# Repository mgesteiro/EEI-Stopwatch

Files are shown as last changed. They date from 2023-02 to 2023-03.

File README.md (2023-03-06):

# EEI-Stopwatch
Open-source and open-hardware stopwatch for [UVigo's E.E.I. Robotic Competition](https://eei.robots.webs.uvigo.es/).

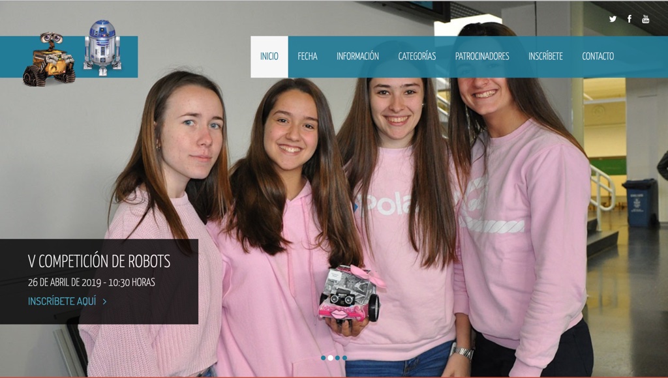
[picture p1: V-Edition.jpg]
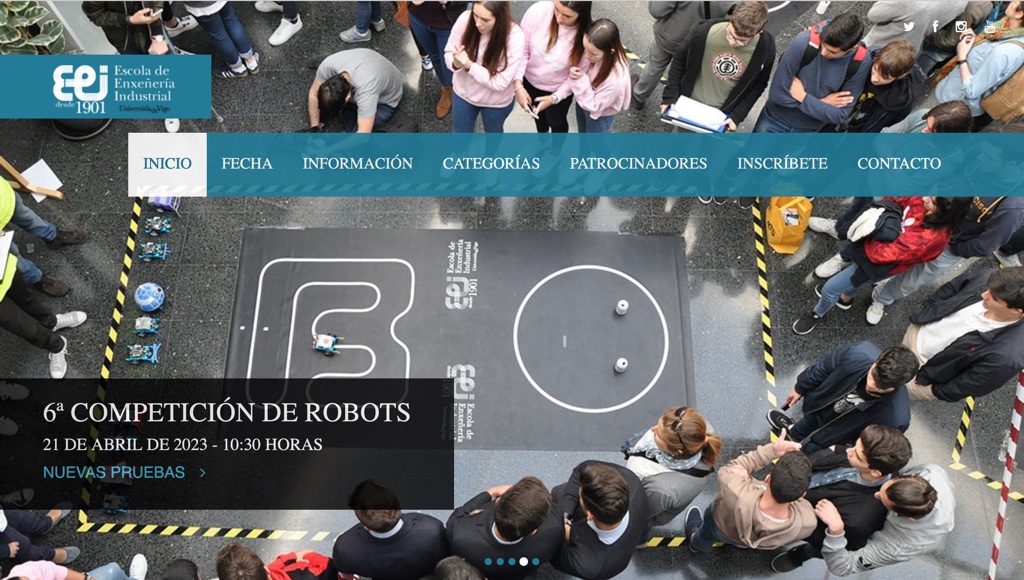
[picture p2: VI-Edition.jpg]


This project has been updated and improved for the **2023 VI edition** of the competition, including a new laser sensor (more accurate and less sensitive to interferences) and a new code base, making it easier to understand, use, configure and adapt.

It's been designed and executed with a minimalistic -yet **highly functional**- intention (it's NOT a toy) while preserving the ***tinkering & learning Maker mindset***, very appropiate and related to the competition nature and goals.

## HOW IT WORKS
The working principle of the **EEI-Stopwatch** is quite simple, although the logic becomes *tricky* easily:

* All the information is shown in a 4-digit 7-segment LED display (*output*).
* User actions are received via a two momentary buttons analog keypad (*input*).
* It has a Tof Laser sensor that measures the distance to the nearest object in front of it continuously.
* When this distance is bellow a configured value, i.e., when ***something passes in front of it***, a detection is triggered: `TDISTANCE` (20 cm by default).
* It gives some room for the object to pass completely to avoid repetitive triggering: `DCWINDOW` (1.9 s by default).
* It uses the internal clock of the microcontroller to measure times.
* It times up to as many laps as configured: `NUMLAPS` (4 by default).
* It shows temporarily the time for each lap after measuring it: `SLWINDOW` (2 s by default).

## OPERATION
The use of the **EEI-Stopwatch** is fairly straightforward and can be done mostly intuitively, but these are the detailed steps:

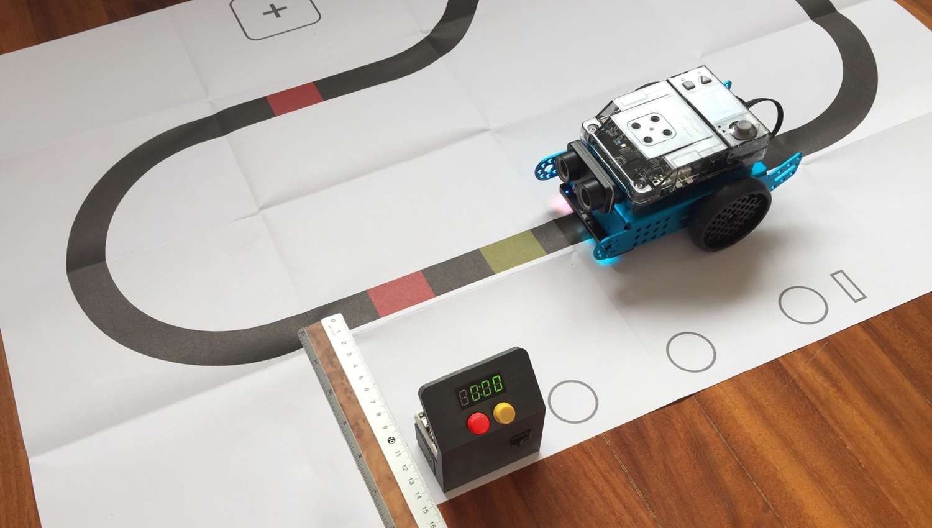
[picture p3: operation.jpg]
Operation


1. **Turn it ON** using the main frontal switch (position *1*): you should see a start-up animation (a *racing LED*). If any problem is detected, an error message will be shown, indicating that the device must be checked/serviced. Make sure also that it is correctly charged!
2. Once started, the EEI-Stopwatch is in ***Distance Measuring Mode***: it shows the distance -in centimeters- to the nearest object in front of the sensor.
	* Use this to **position it about 15-20 cm** from the *racing line*: use your own hand as reference for the sensor. Ideally, position it in the side of a straitgh line, perpendicular to it (like in the picture).
	* Once positioned, **clear all the objects** in front of it (to avoid *false triggers*) and **press the yellow button** to initiate the ***Stopwatch Mode***.
3. Once in the ***Stopwatch Mode***, the time won't start until it detects a *passing object* (anything at less than 20 cm): it's time to put the robot in the track -behind the stopwatch line- and start it (racing time!).
	* When the **robot is detected** (as passing in front of it), the stopwatch **starts measuring** the time, and does so until the robot is detected again, **storing the lap time** in that precise moment.
	* After each lap, the stopwatch **shows temporarily the previous lap time** (during 2 seconds) and then continues to show the current lap time, until the robot is detected again, repeating the process.
	* There are two possible options now: you can **wait until the robot completes all the laps** that the EEI-Stopwatch can measure in one go (4 by default), or you can **press the yellow button to abort** the process (discarding the current lap). In either case, the EEI-Stopwatch enters the ***Results Mode***.
4. In the ***Results Mode***, you can review all the lap times stored in this go: press the yellow button to cycle through them. Take into account that if the process was aborted, some of the laps may have a *0:00* time.
5. **RESET:** if you **long-press** the red button (during 1 second at least), the EEI-Stopwatch is reset, clearly showing it with a *RESET animation*, and entering the ***Stopwatch Mode*** again (step 3).

**CHARGING:** The EEI-Stopwatch is **battery-powered** (an 18650 Li-ion cell), and can be recharged using any typical 5V micro-USB mobile charger: plug it in the micro-USB connector of the case and watch how the status light changes (through the small hole by its side). NOTE: pay attention to not confuse the USB connector in the Arduino Nano with the one corresponding to the battery charger.

**RESOLUTION:** The EEI-Stopwatch has a configured **maximum resolution of ~5 hundredths** of a second (i.e. 50 ms), determined mostly by the Laser sensor, as the result of a balance between accuracy, interference resilience and responsiveness. It is more than good enough for our application, but feel free to read about it in the configuration section of the code and fine-tune it to your needs.

## 3D

All the **3D parts** (available in the [`3D`](3D) folder) were created using the open-source and free software [FreeCAD](https://www.freecad.org). You can find there also all the STL files ready to be sliced and 3D printed, with **no supports** required at all: it's a very easy print.

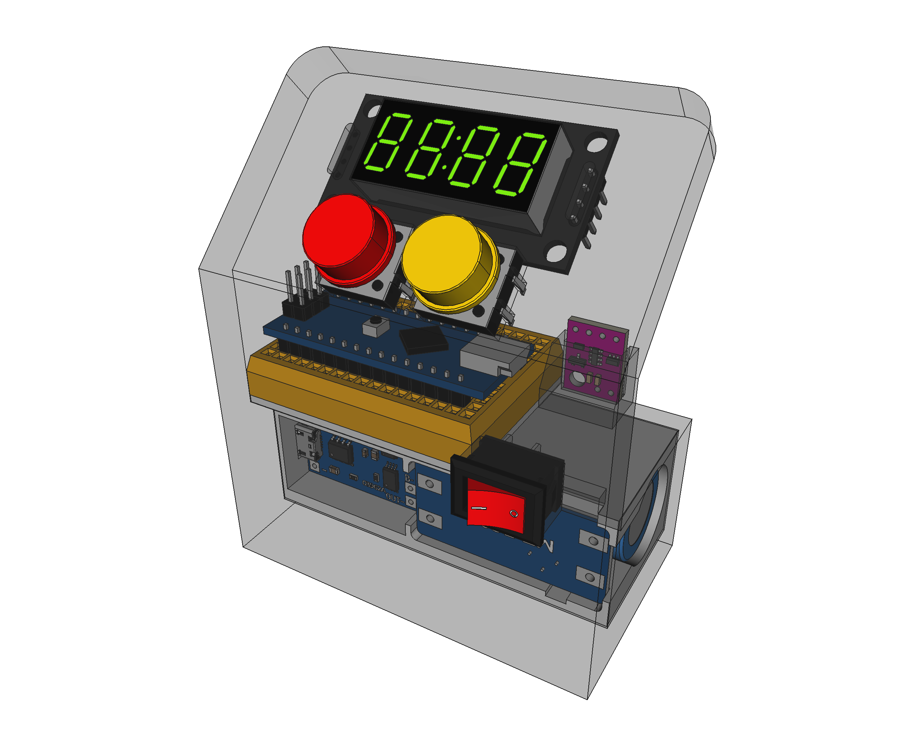
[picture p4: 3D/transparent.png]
transparent


Before printing the pieces, make sure that the dimensions of the electronic parts match: tolerances of the 3D models are *quite tight* and I've already found modules with huge differences in size.

## ELECTRONICS

This is the schematic of the system, created using the open-source software [Fritzing](https://fritzing.org) and available in the [`electronics`](electronics) folder.



The bottom part is the **powerbank** subsystem that provides 5V to the device and is rechargable (using any *typical* 5V micro-USB mobile charger). The top part contains the **4-digit display**, the **ToF laser sensor** and the **analog keypad** (two buttons) along with the **main microcontroller** (an Arduino Nano).

## CODE

The EEI-Stopwatch is powered by an **Arduino Nano** which can be programmed with the [Arduino IDE](https://www.arduino.cc/en/software). The code is **thoroughly commented and documented**, and available in the [`code/chrono`](code/chrono) folder:

* There are a number of configuration parameters at the beggining of the `chrono.ino` file, if you wan't to fine-tune or adapt the operation to your needs (e.g. the number of laps to store, or the different clearing windows).
* Requires two external libraries: [TM1637TinyDisplay](https://github.com/jasonacox/TM1637TinyDisplay) and [VL53L0X](https://github.com/pololu/vl53l0x-arduino) (directly available within the Arduino IDE library manager).
* Includes also two local *ad-hoc* libraries: **`AKeypad-lib.h`** and **`Stopwatch.h`** (both *self-explanatory*)

## ASSEMBLY

In the [`assembly`](assembly) folder there is a 20 step guide to assemble the **EEI-Stopwatch**, including the powerbank itself.

**NOTE:** the assembly guide hasn't been updated to the latest 2023 revision but is still mostly relevant as only two things changed

* The IR sensor has been changed by a ToF Laser sensor
* Some of the connections have been updated accordingly (see the [new schematic](#electronics))

## REFERENCES

* UVigo's E.E.I. Robotic Competition: [eei.robots.webs.uvigo.es](https://eei.robots.webs.uvigo.es/)
* 4-digit 7-segment LED display library: [github.com/jasonacox/TM1637TinyDisplay](https://github.com/jasonacox/TM1637TinyDisplay)
* VL53L0X Tof Laser Sensor library: [github.com/pololu/vl53l0x-arduino](https://github.com/pololu/vl53l0x-arduino)
* VL53L0X ToF Laser Sensor datasheet: [www.digikey.com/en/datasheets/stmicroelectronics/stmicroelectronics-endm00279086](https://www.digikey.com/en/datasheets/stmicroelectronics/stmicroelectronics-endm00279086)
* My FreeCAD 3D models repository: [github.com/mgesteiro/FreeCAD-models](https://github.com/mgesteiro/FreeCAD-models)
* My Fritzing parts repository: [github.com/mgesteiro/fritzing-parts](https://github.com/mgesteiro/fritzing-parts)
* **FreeCAD** 3D CAD modelling software: [www.freecad.org](https://www.freecad.org)
* **Fritzing** schematics and PCB modelling software: [fritzing.org](https://fritzing.org)

## LICENSE

This work is licensed under the [GNU General Public License v3.0](LICENSE-GPLV30). All media and data files that are not source code are licensed under the [Creative Commons Attribution 4.0 BY-SA license](LICENSE-CCBYSA40).

More information about licenses in [Opensource licenses](https://opensource.org/licenses/) and [Creative Commons licenses](https://creativecommons.org/licenses/).

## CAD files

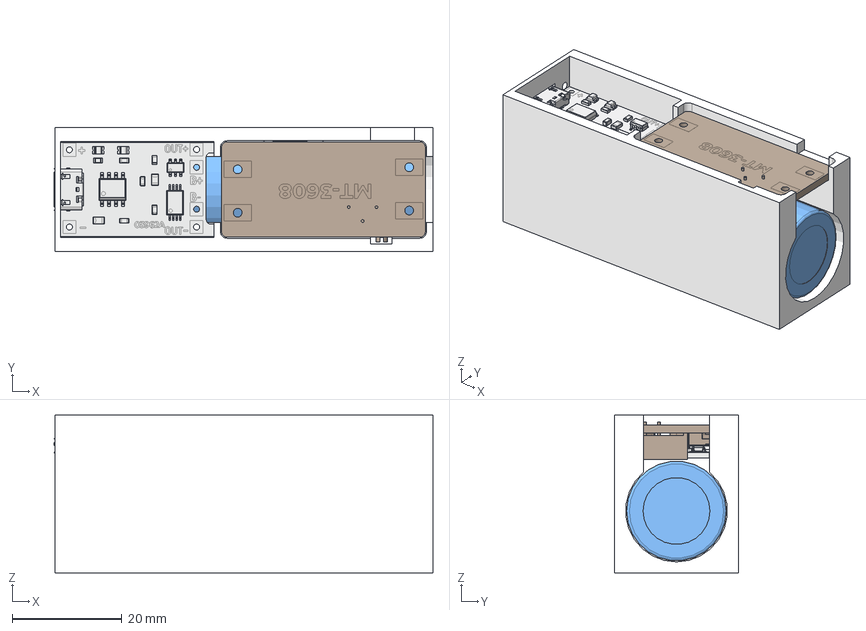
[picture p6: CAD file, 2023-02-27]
3D/powerBank.FCStd
69.2 x 22.6 x 28.8 mm
03962A
MT-3608
Body-powerBank

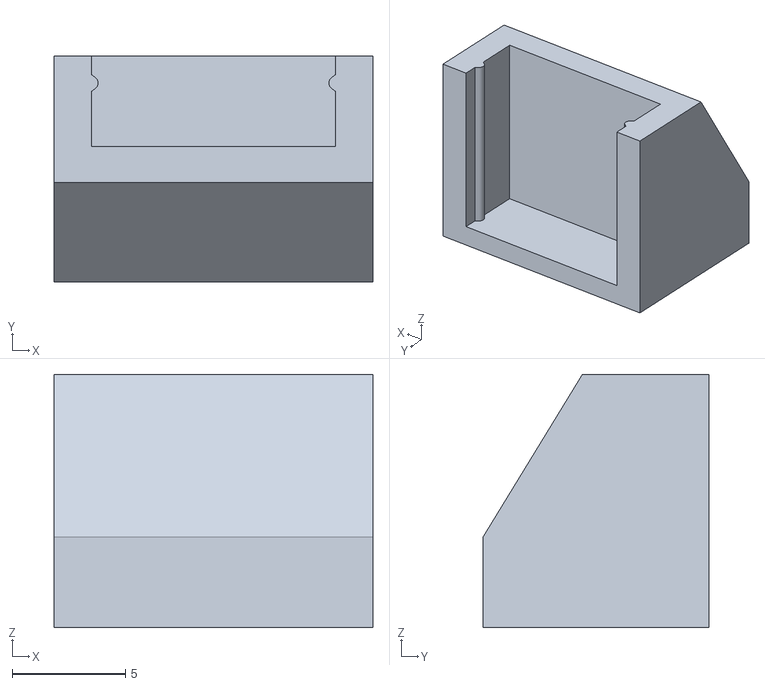
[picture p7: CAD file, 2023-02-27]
3D/tofsupport.stl
14.1 x 10.0 x 11.2

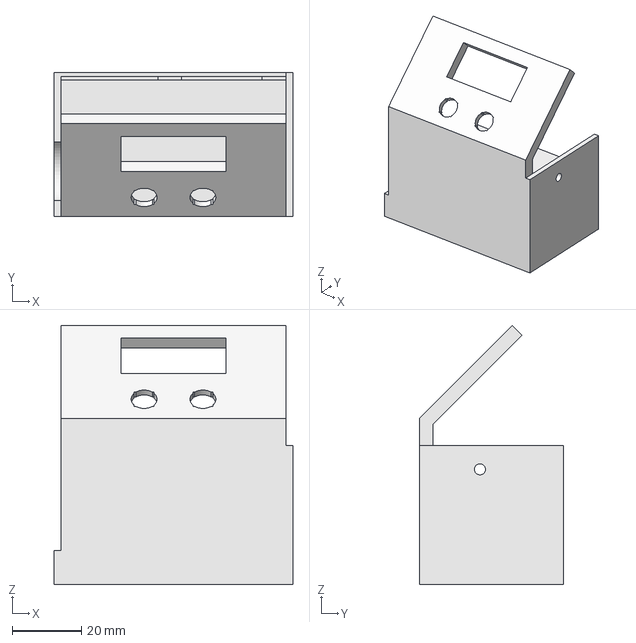
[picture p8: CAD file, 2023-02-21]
3D/chasis.FCStd
69.0 x 41.7 x 74.9 mm

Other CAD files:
3D/chasis.stl
3D/powerBank.stl

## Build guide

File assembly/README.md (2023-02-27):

# EEI-Stopwatch assembly GUIDE
Stopwatch for [UVigo's E.E.I. Robotic Competition](https://eei.robots.webs.uvigo.es/).

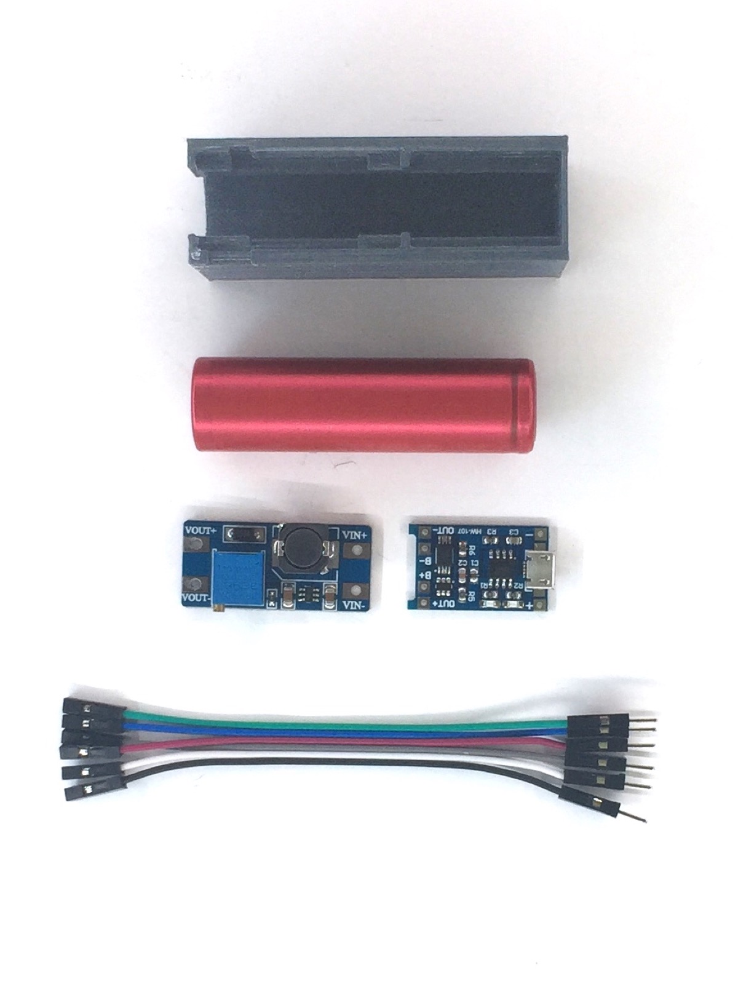
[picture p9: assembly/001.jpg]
Step-01


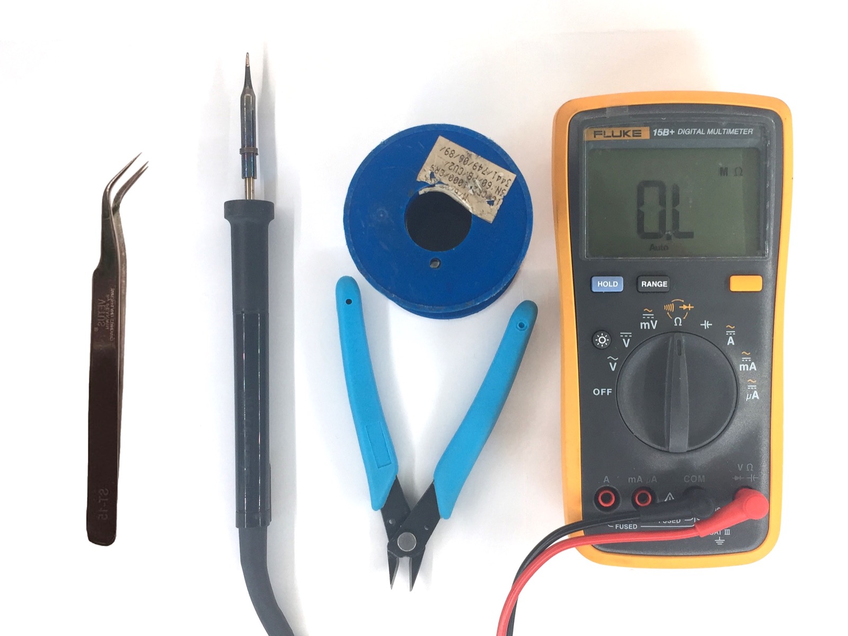
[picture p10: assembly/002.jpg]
Step-02


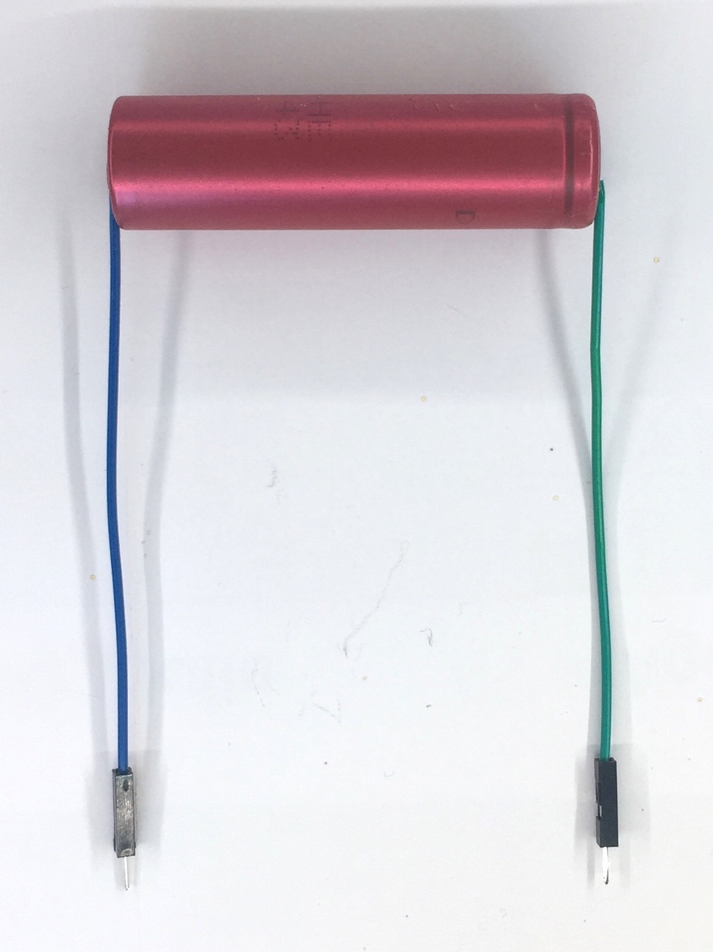
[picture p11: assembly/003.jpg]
Step-03


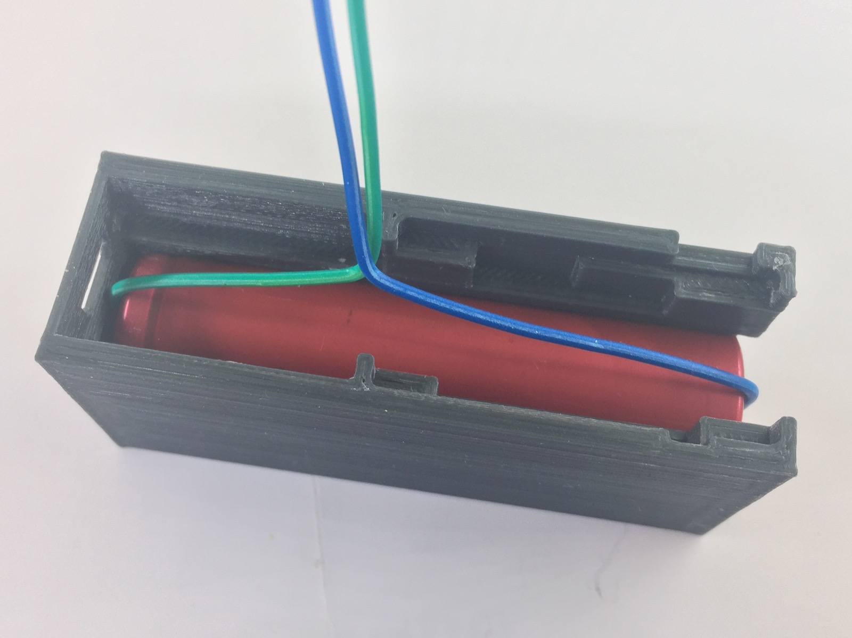
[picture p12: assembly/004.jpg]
Step-04


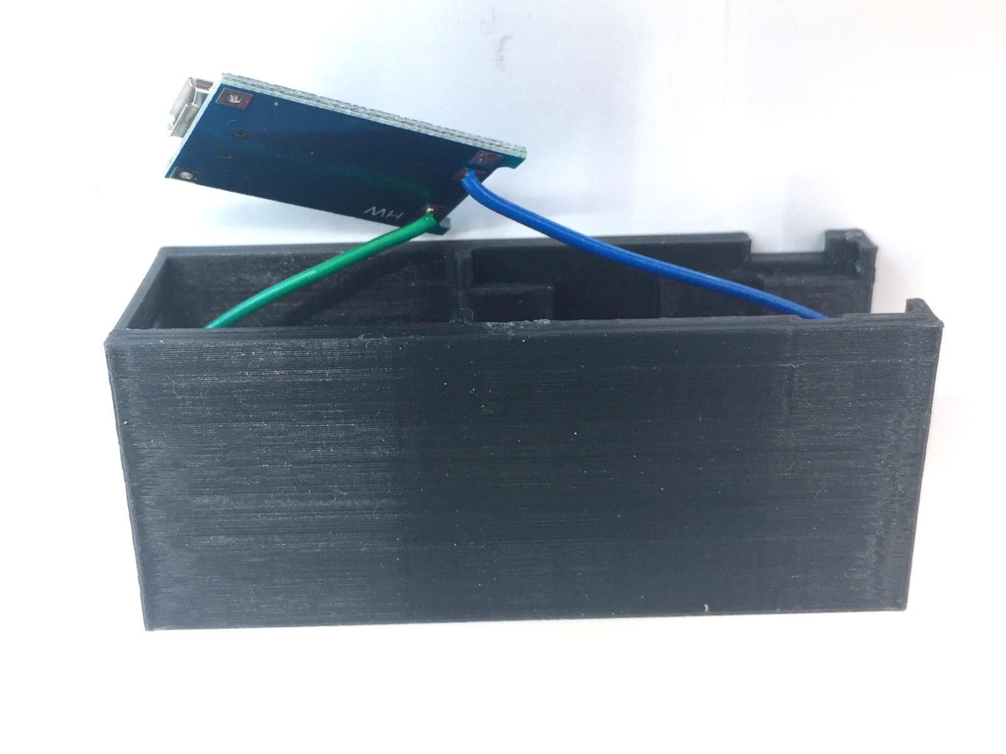
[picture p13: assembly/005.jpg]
Step-05


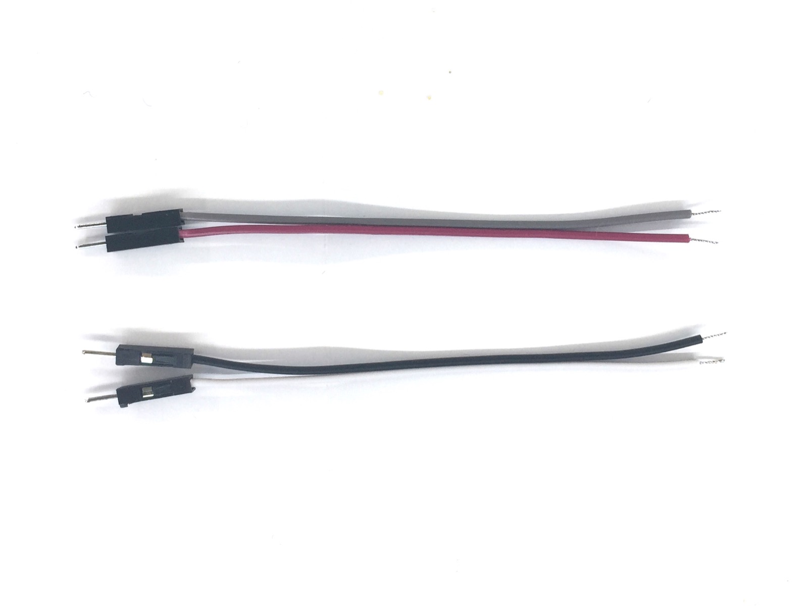
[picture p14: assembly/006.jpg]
Step-06


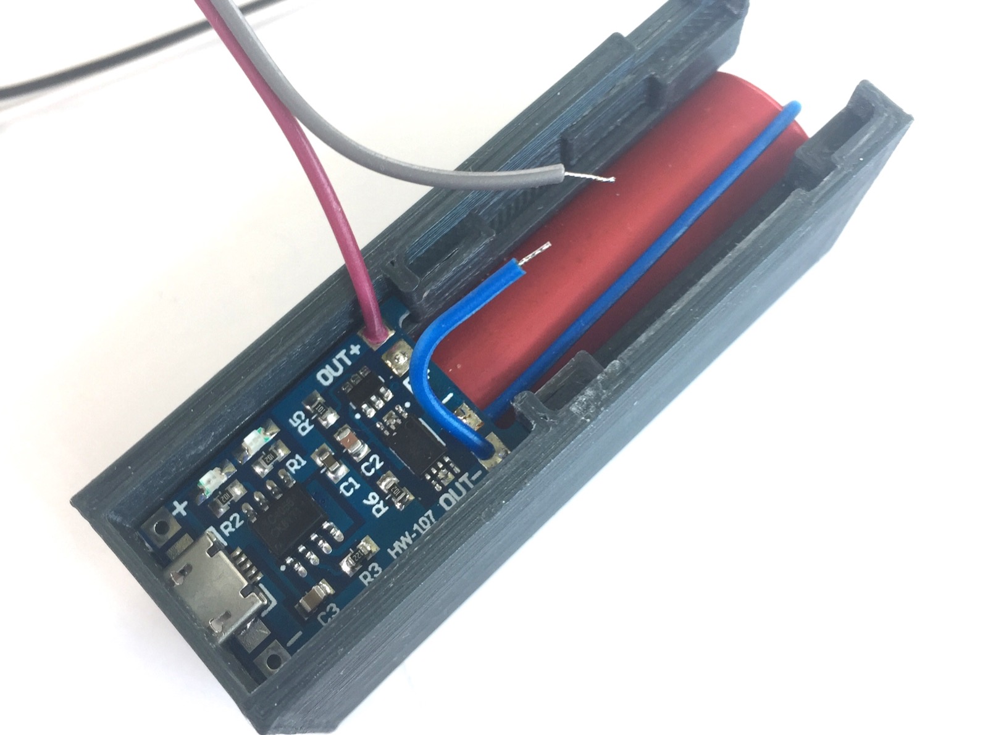
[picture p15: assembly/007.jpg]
Step-07


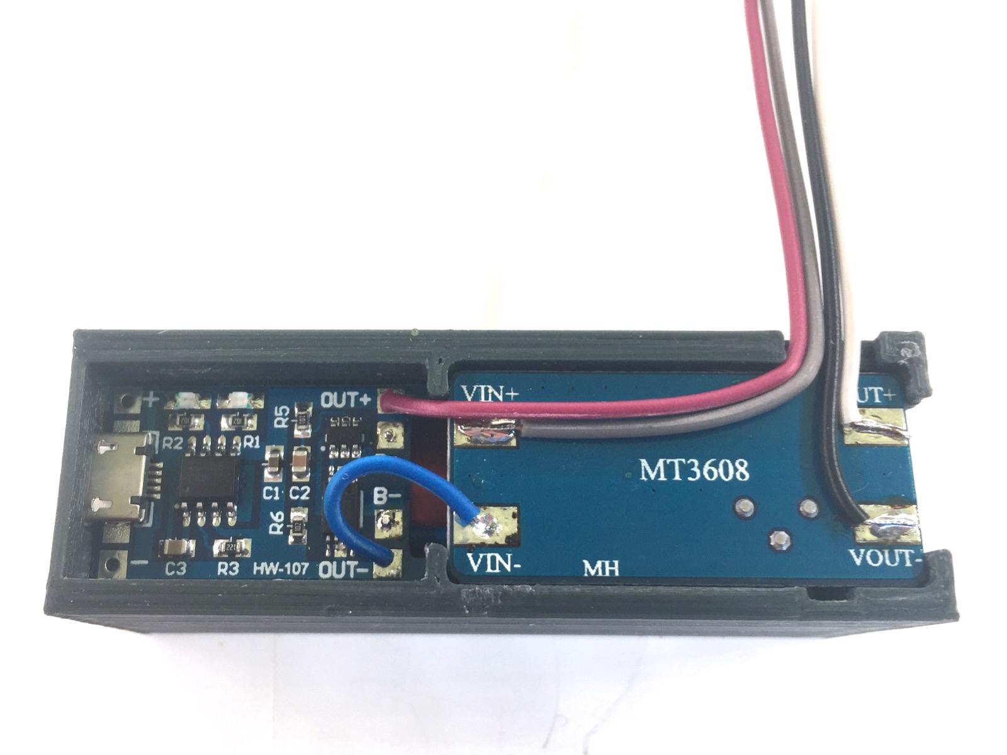
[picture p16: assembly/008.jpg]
Step-08


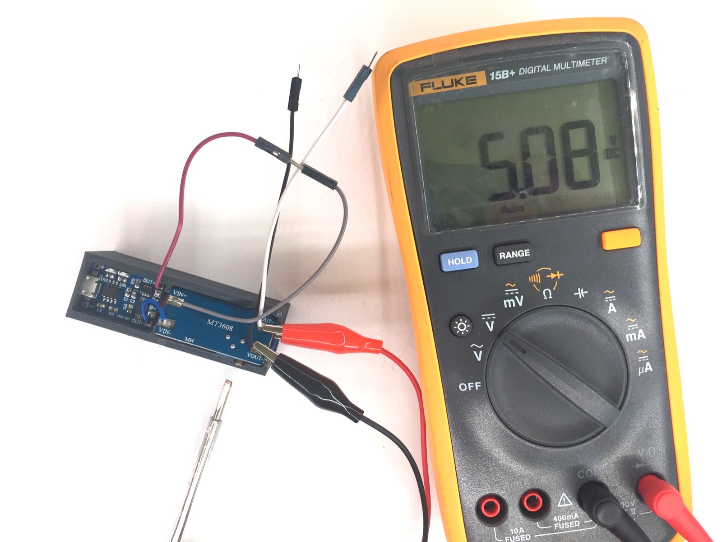
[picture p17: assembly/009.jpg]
Step-09


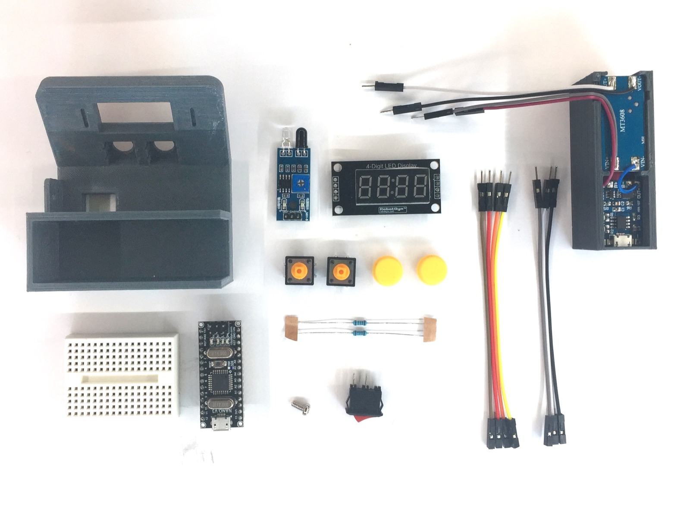
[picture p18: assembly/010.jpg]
Step-10


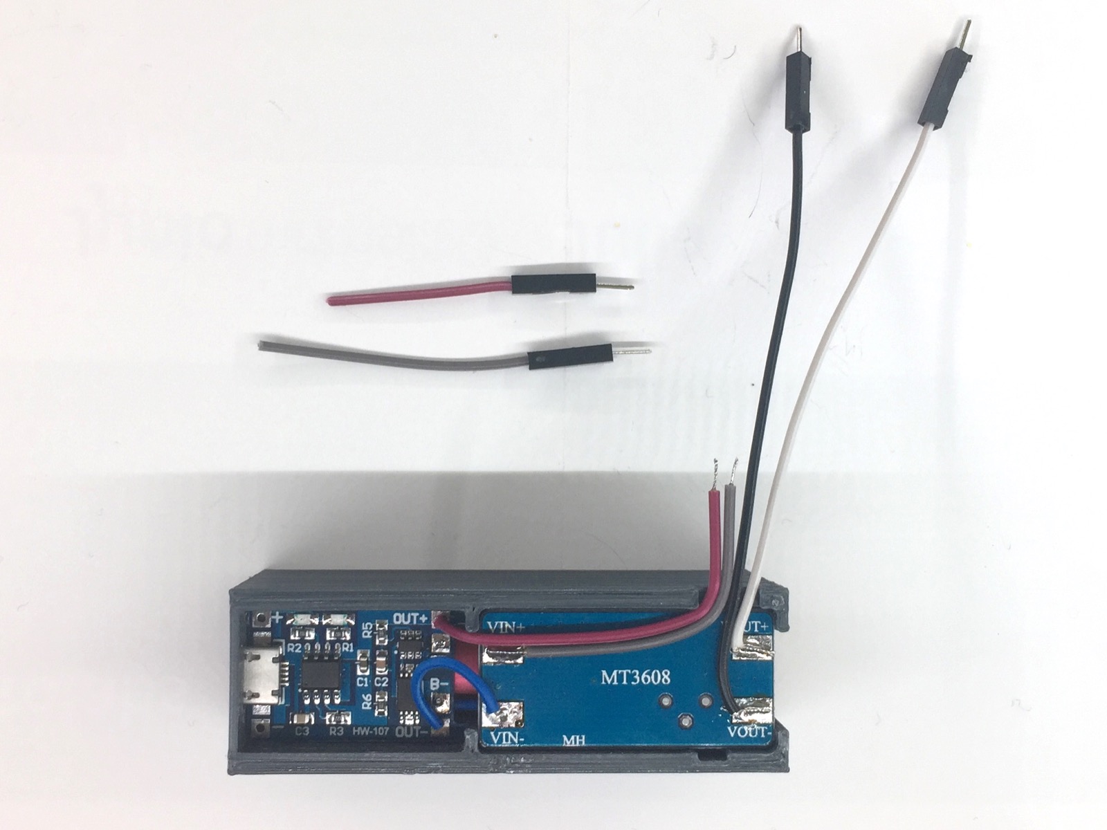
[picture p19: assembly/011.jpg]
Step-11


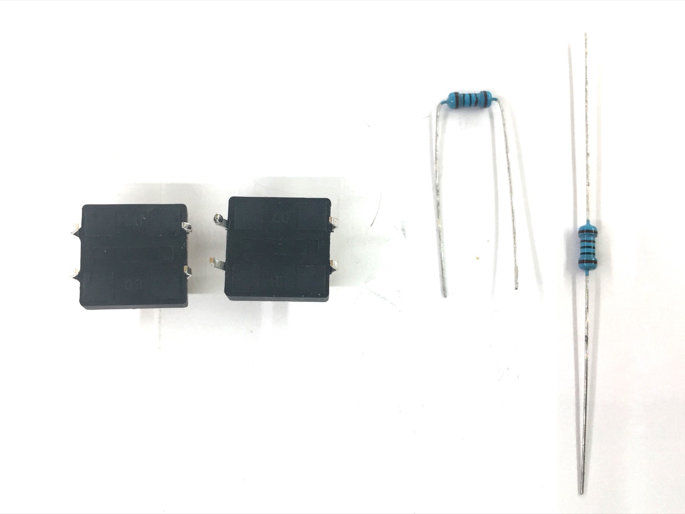
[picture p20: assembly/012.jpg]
Step-12


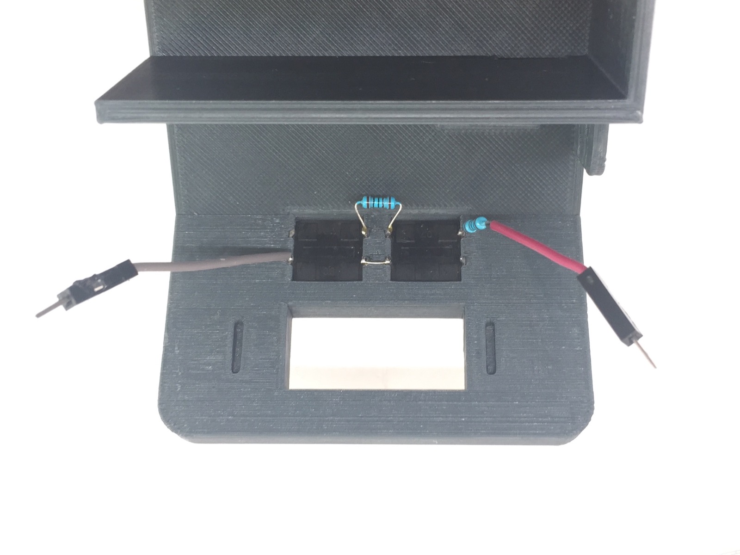
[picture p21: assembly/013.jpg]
Step-13


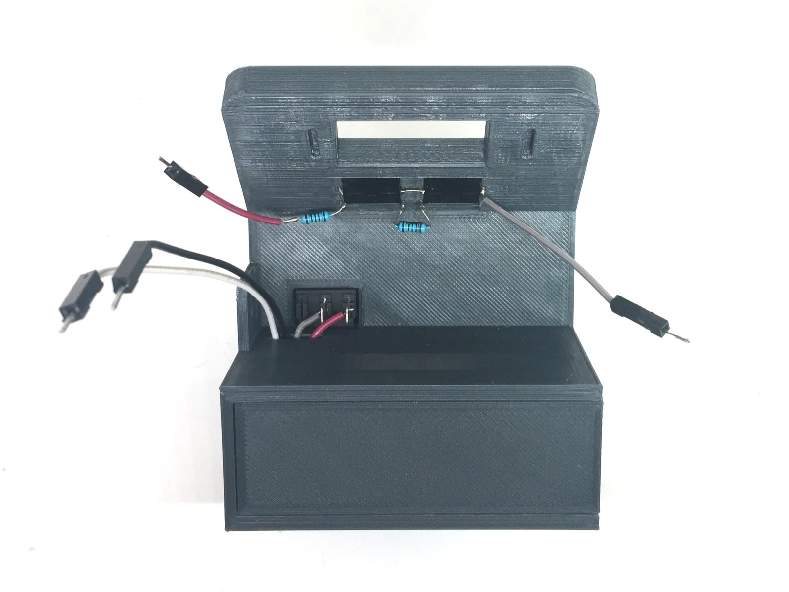
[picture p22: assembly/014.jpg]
Step-14


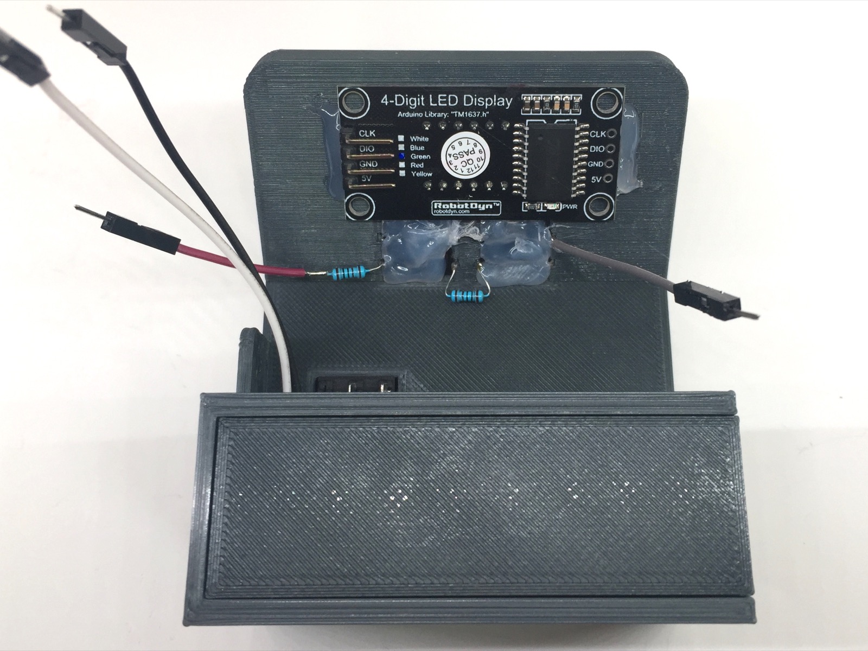
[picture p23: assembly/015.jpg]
Step-15


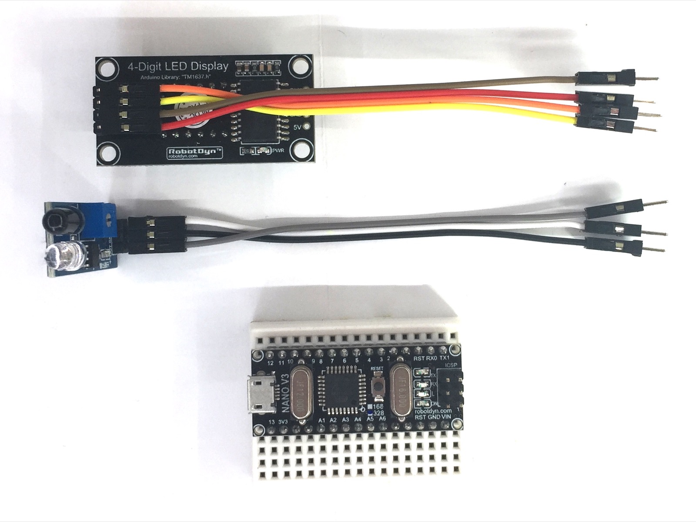
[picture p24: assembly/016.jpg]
Step-16


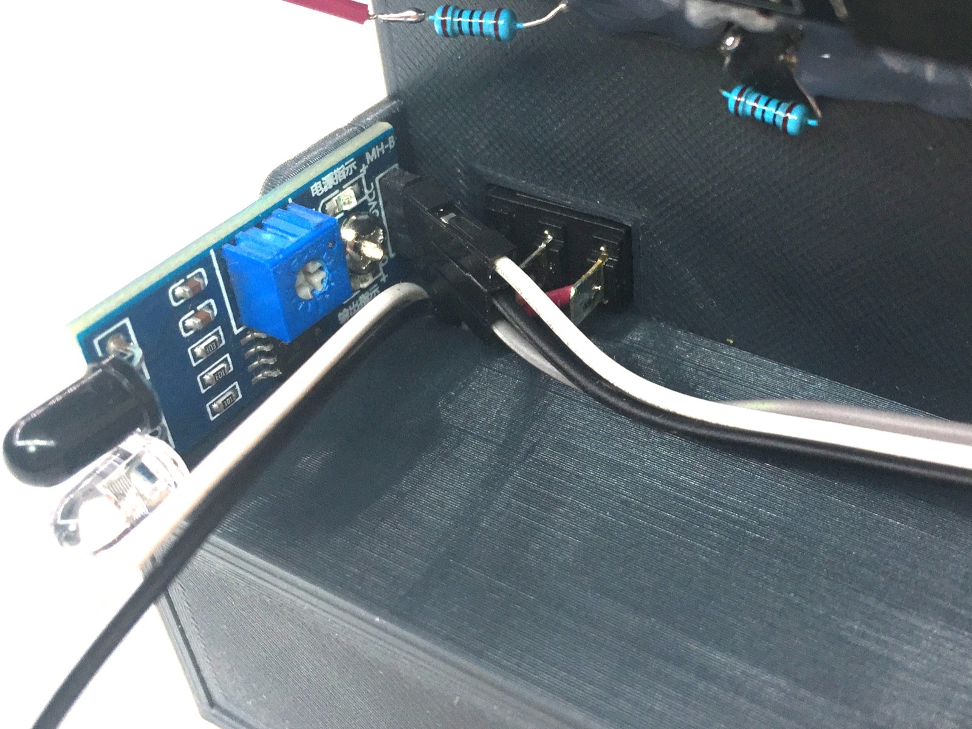
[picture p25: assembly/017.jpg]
Step-17


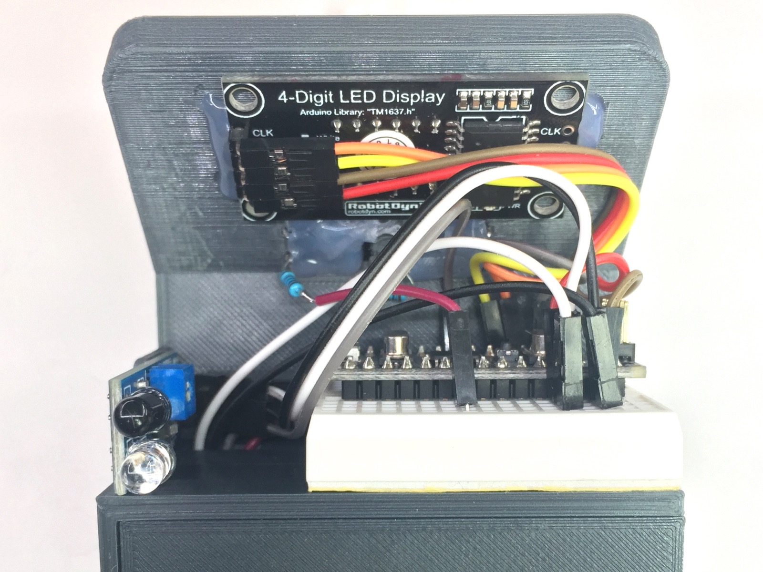
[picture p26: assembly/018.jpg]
Step-18


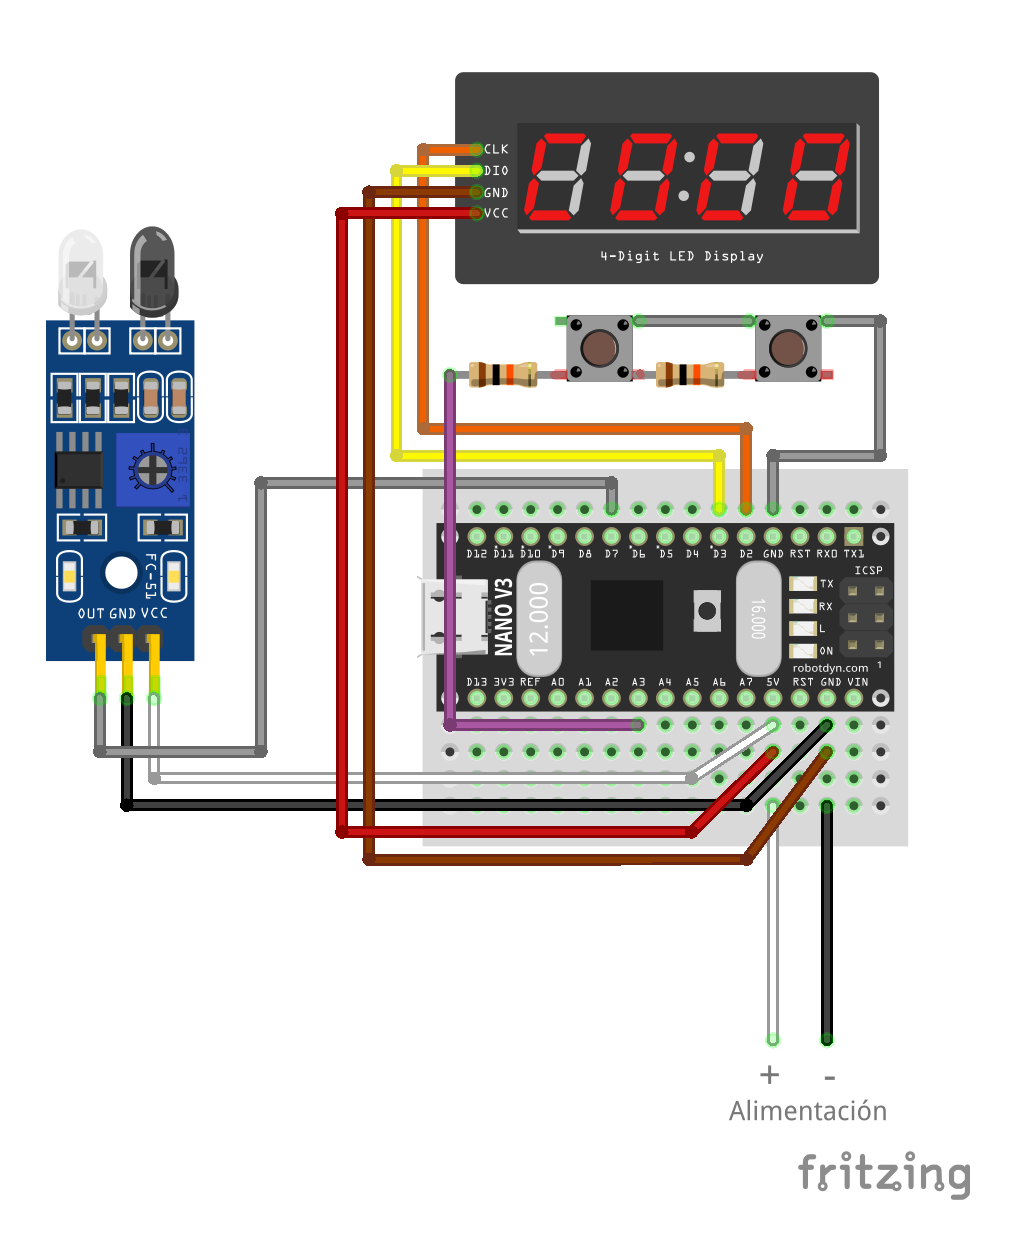
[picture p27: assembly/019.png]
Step-19


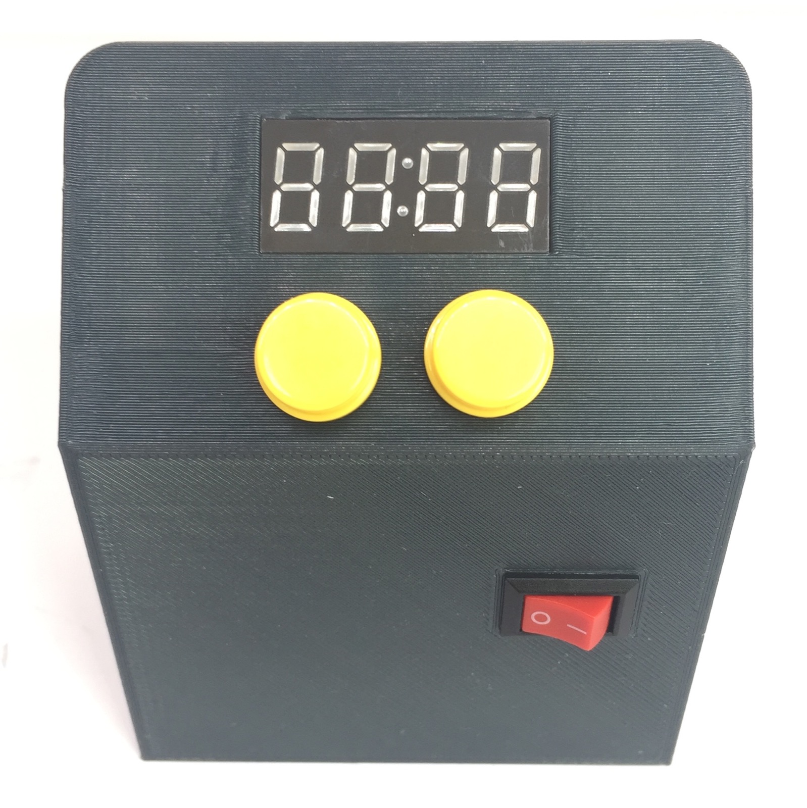
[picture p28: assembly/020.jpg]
Step-20


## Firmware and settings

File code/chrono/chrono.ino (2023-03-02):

/**
 * E.E.I. Stopwatch
 * A stopwatch for UVigo's E.E.I. Robotic Competition - https://eei.robots.webs.uvigo.es/
 *
 * @file      EEI-Stopwatch.ino
 * @author    mgesteiro
 * @date      20231702
 * @version   1.0.0
 * @copyright mgesteiro, OpenSource with LICENSE GPLv3
 * @note      Required libraries: TM1637TinyDisplay, Pololu's VL53L0X
 */

#define PROGRAM "E.E.I. Stopwatch"
#define VERSION "1.0.0"

// Configuration
#define NUMLAPS  4     // Number of Laps to store (maximum 10)
#define TRIGGERD 200   // Trigger Distance in mm: less than this is considered a "detection"
#define DCWINDOW 1900  // Detect Clear Window in ms: no more detections triggered during this time
#define SLWINDOW 2000  // Show Lap Window in ms: how long we show previous lap time while counting

/* Advanced: timing resolution
 * This is the 'time budget' value for the ToF laser sensor: time allowed to measure a distance.
 * The minimum value depends on the hardware revision (18700 in my case). Check your vendor's datasheet.
 * The bigger the number, the more accurate it gets measuring the distance and the less prone to
 * interference, but also the less responsive it becomes, as it requires more time for each measure.
 * The default factory value is ~33000 (i.e. ~33 ms). A value of 20000 means that the fastest it can
 * take a measure is 20 ms, thus becoming by de facto the maximum stopwatch timing resolution.
 * Use a value of 0 to let the device use its factory default.
 */
#define RESOLUTION 50000  // in µs

// Includes
#include <Arduino.h>
#include "Stopwatch.h"
#include "AKeypad-lib.h"
#include <TM1637TinyDisplay.h>
#include <VL53L0X.h>

// Stopwatch
Stopwatch sw(NUMLAPS);
uint8_t whatLap = 0;
uint32_t finishShowLapTime = 0;

// Keypad
#define AKP_PIN A3
#define K_YELLOW 1
#define K_RED 2
const int16_t AKP_VALUES[] = {550, 390};  // 22Kohm resistors
AKeypad keypad(AKP_PIN, 2, AKP_VALUES);


// TM1637TinyDisplay - 4 Digit Display
#define CLK 2
#define DIO 3
TM1637TinyDisplay display(CLK, DIO);

// Initial animation
// @see https://jasonacox.github.io/TM1637TinyDisplay/examples/7-segment-animator.html
const uint8_t INTRO_A[][4] PROGMEM = {
	{ 0x00, 0x00, 0x00, 0x00 },
	{ 0x10, 0x00, 0x00, 0x00 },
	{ 0x20, 0x00, 0x00, 0x00 },
	{ 0x01, 0x00, 0x00, 0x00 },
	{ 0x00, 0x01, 0x00, 0x00 },
	{ 0x00, 0x00, 0x01, 0x00 },
	{ 0x00, 0x00, 0x00, 0x01 },
	{ 0x00, 0x00, 0x00, 0x02 },
	{ 0x00, 0x00, 0x00, 0x04 },
	{ 0x00, 0x00, 0x00, 0x08 },
	{ 0x00, 0x00, 0x08, 0x00 },
	{ 0x00, 0x08, 0x00, 0x00 },
	{ 0x00, 0x10, 0x00, 0x00 },
	{ 0x00, 0x20, 0x00, 0x00 },
	{ 0x00, 0x01, 0x00, 0x00 },
	{ 0x00, 0x00, 0x01, 0x00 },
	{ 0x00, 0x00, 0x02, 0x00 },
	{ 0x00, 0x00, 0x04, 0x00 },
	{ 0x00, 0x00, 0x08, 0x00 },
	{ 0x00, 0x08, 0x00, 0x00 },
	{ 0x08, 0x00, 0x00, 0x00 },
	{ 0x10, 0x00, 0x00, 0x00 },
	{ 0x20, 0x00, 0x00, 0x00 },
	{ 0x01, 0x00, 0x00, 0x00 },
	{ 0x00, 0x01, 0x00, 0x00 },
	{ 0x00, 0x00, 0x01, 0x00 },
	{ 0x00, 0x00, 0x00, 0x01 },
	{ 0x00, 0x00, 0x00, 0x02 },
	{ 0x00, 0x00, 0x00, 0x04 },
	{ 0x00, 0x00, 0x00, 0x08 },
	{ 0x00, 0x00, 0x08, 0x00 },
	{ 0x00, 0x08, 0x00, 0x00 },
	{ 0x08, 0x00, 0x00, 0x00 },
	{ 0x18, 0x00, 0x00, 0x00 },
	{ 0x38, 0x00, 0x00, 0x00 },
	{ 0x39, 0x00, 0x00, 0x00 },
	{ 0x39, 0x01, 0x00, 0x00 },
	{ 0x39, 0x01, 0x01, 0x00 },
	{ 0x39, 0x01, 0x01, 0x01 },
	{ 0x39, 0x01, 0x01, 0x03 },
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
};
// Reset animation
const uint8_t RESET_A[][4] PROGMEM = {
	{ 0x00, 0x06, 0x30, 0x00 },
	{ 0x00, 0x46, 0x70, 0x00 },
	{ 0x40, 0x06, 0x30, 0x40 },
	{ 0x30, 0x06, 0x30, 0x06 },
	{ 0x30, 0x30, 0x06, 0x06 },
	{ 0x36, 0x00, 0x00, 0x36 },
	{ 0x30, 0x00, 0x00, 0x06 },
	{ 0x00, 0x00, 0x00, 0x00 }
};

// VL53L0X ToF sensor
VL53L0X tof;
uint32_t detectionClearTime = 0;

// working modes
uint8_t wmode = 0;
#define M_DISTANCE 1
#define M_STOPWATCH 2
#define M_RESULTS 3


/*********************************************************************************************
 *
 *   S E T U P   &   L O O P
 *
 */

void setup() {
	// Serial port banner
	Serial.begin(115200);
	Serial.print(PROGRAM);
	Serial.print(" [v");
	Serial.print(VERSION);
	Serial.println("]");
	Serial.println("Configuration: ");
	Serial.print("  Laps: ");
	Serial.println(NUMLAPS);
	Serial.print("  Trigger distance: ");
	Serial.println(TRIGGERD);
	Serial.print("  Detect clear window: ");
	Serial.println(DCWINDOW);
	Serial.print("  Show lap window: ");
	Serial.println(SLWINDOW);
	Serial.print("  Timing resolution: ");
	Serial.print(RESOLUTION);
	Serial.print(" [");

	// Keypad
	keypad.init();

	// TM1637 display
	display.begin();
	display.setBrightness(BRIGHT_7);

	// VL53L0X
	Wire.begin();
	tof.setTimeout(500);
	if (! tof.init())
	{
		Serial.println("Failed to detect and initialize ToF sensor!");
		display.showString("toFE");
		while(1);  // HALT 
	}
	tof.setMeasurementTimingBudget(RESOLUTION);  // defined in the configuration section
	Serial.print(tof.getMeasurementTimingBudget()); Serial.println("]");  // show real configured value
	tof.startContinuous();  // start measuring distance

	// Animation sequence in PROGMEM flash memory
	display.showAnimation_P(INTRO_A, FRAMES(INTRO_A), TIME_MS(30));
	delay(300);

	// initial mode
	wmode = M_DISTANCE;
}  // setup()

void loop() {
	uint32_t currenTime = millis();

	// watch keypad and process actions
	uint8_t kp_code = keypad.handleKeypad(currenTime);
	if (kp_code) processKeyEvent(kp_code);

	// Operate depending on the mode:
	//
	// DISTANCE mode: show distance to help position the device
	if (wmode == M_DISTANCE)
	{
		showDistance(tof.readRangeContinuousMillimeters());
	} else
	//
	// STOPWATCH mode: show stopwatch
	if (wmode == M_STOPWATCH)
	{
		if (isDetected(currenTime))
		{
			if (! sw.running()) sw.start();  // start counting
			else
			{
				sw.lap();  // time the lap
				finishShowLapTime = currenTime + SLWINDOW;  // when to stop showing the new lap time
				if (! sw.running())
				{
					// storage space depleted, i.e. it was the last lap
					showTime(sw.getTime());  // update display
					delay(SLWINDOW);  // show it the same amount of time as any lap
					display.showString(" End");  // indicate it has finished
					wmode = M_RESULTS;  // go to results mode
				}
			}
		}
		if (sw.running())
			if (currenTime < finishShowLapTime) showTime(sw.getPreviousLapTime());  // still showing last lap time
			else showTime(sw.getTime());  // live timing
	} /* else
	//
	// RESULTS mode: show results
	if (wmode == M_RESULTS)
	{
		nothing to do here because all actions are related to events driven by
		the keypad, that has already been handled at the beginning of this loop.
	}
	*/
}  // loop()

/*********************************************************************************************
 *
 *   S U P P O R T   F U N C T I O N S
 *
 */

/**
 * Displays the provided time in human readable format: Seconds:Tenths  // no leading "0"
 *
 * @param lapTime  Time to be shown, in milliseconds.
 */
void showTime(uint32_t lapTime)
{
	uint8_t segments[4];
	for (int8_t i = 3; i >= 0; i --)
	{
		lapTime /= 10; // we do this beforehand because only 4 digits needed <- discard last position
		segments[i] = display.encodeDigit(lapTime % 10);
	}
	if (lapTime == 0) segments[0] = 0;  // delete unnecessary leading 0
	segments[1] |= SEG_DP;  // active colon
	display.setSegments(segments);  // show data
}

/**
 * Displays the provided distance (in cm).
 *
 * @param distance Distance in milimiters to be converted and displayed
 */
void showDistance(int16_t distance)
{
	distance /= 10;  // convert to cms
	display.showString("d", 1, 1, B10000000);  // "d:"
	display.showNumber(distance, false, 2, 2);  // two last display digits
}

/**
 * Displays the indicated lap time, showing before briefly the lap number.
 *
 * @param lap Which lap to show.
 */
void showLapTime(uint8_t lap)
{
	display.clear();
	// show lap indicator first briefly
	display.showString("L", 1, 1); // "L"
	display.showNumber(lap+1, false, 1, 2);
	delay(350);
	// show finally the lap time
	showTime(sw.getLapTime(lap));
}

/**
 * High level function that contains the logic to process the keypad actions/events.
 *
 * @param kp_code packed byte returning from the handleKeyPad() function
 *                lo nibble -> key code,  hi nibble -> event [T_AKP_EVENTS]
 */
void processKeyEvent(uint8_t kp_code)
{
	uint8_t key, event;
	key = kp_code & B00001111; // lower nibble
	event = kp_code >> 4;  // upper nibble

	// SHORT key press
	if (event == AKP_EVT_PRESSED)
	{
		if (wmode == M_DISTANCE && key == K_YELLOW)
		{
			// change to STOPWATCH mode
			wmode = M_STOPWATCH;
			showTime(0);
			return;
		}
		if (wmode == M_STOPWATCH && key == K_YELLOW && sw.running())
		{
			// stop stopwatch and go to results
			sw.abort();
			wmode = M_RESULTS;
			display.showString(" End");  // indicate it has finished
			return;
		}
		if (wmode == M_RESULTS && key == K_YELLOW)
		{
			// show lap time
			showLapTime(whatLap);
			// select next lap
			whatLap ++;
			if (whatLap >= NUMLAPS) whatLap = 0;
		}
	} else
	// LONG key press
	if (event == AKP_EVT_LONGPRESSED)
	{
		if ((wmode == M_STOPWATCH || wmode == M_RESULTS) && key == K_RED)
		{
			// reset stopwatch
			sw.reset();
			whatLap = 0;
			display.showAnimation_P(RESET_A, FRAMES(RESET_A), TIME_MS(30));
			showTime(0);
			wmode = M_STOPWATCH; // assert STOPWATCH mode
		}
	}
} // processKeyEvent()

/**
 * Check the sensor with a security margin/window.
 *
 * @param currentTime current time in milliseconds 
 * @return true if an object is nearer than the threshold distance and the security
 *         margin window (in milliseconds) has been cleared. False otherwise.
 */
bool isDetected(uint32_t currentTime)
{
	if (currentTime < detectionClearTime) return false;  // if not clear, quit
	bool result = tof.readRangeContinuousMillimeters() < TRIGGERD;  // something close?
	// update detection clear window
	if (result) detectionClearTime = millis() + DCWINDOW;  // we call millis() because the ToF sensor call is very time-consuming
	return result;
}

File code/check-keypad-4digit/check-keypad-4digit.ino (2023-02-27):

/**
 * Utility to check EEI-Stopwatch keypad
 * For 22kΩ resistors should give ~390 and ~550 values
 */

#include <TM1637TinyDisplay.h>

#define CLK 2
#define DIO 3
TM1637TinyDisplay display(CLK, DIO);

void setup() {
  pinMode(A3, INPUT_PULLUP);
  display.begin();
  display.setBrightness(BRIGHT_7);
}

void loop() {
  display.showNumber(analogRead(A3));
  delay(100);
}

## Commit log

2023-02-21 First 3D model - 20190225
    [chasis.FCStd]
2023-02-21 First 3D model STL - 20190225
    [chasis.stl]
2023-02-21 Second iteration 3D model - 20190305
    [chasis.stl, powerBank.FCStd, powerBank.stl]
2023-02-21 Release for the V EEI Robotic Competition - 20190426
    [Stopwatch.fzz]
2023-02-27 2023 release - VI EEI Robotic Competition
    [EEI-Stopwatch.fzz, Stopwatch.fzz, chasis.stl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]
2023-03-06 updated schematic
    [EEI-Stopwatch.fzz]
